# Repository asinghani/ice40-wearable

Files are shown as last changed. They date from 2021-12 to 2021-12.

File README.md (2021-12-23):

# iCE40 Wearables

This repo contains board designs (KiCad) for two iCE40 FPGA-based boards: one in a sewable form-factor and one in a cat-ear form factor.

### Board 1: Sewable

This board is inspired by the [Adafruit Flora](https://www.adafruit.com/product/659) and is meant to be sewn into clothing or accessories. It is shaped as a small circle and has all the components on the front side to allow it to sit flush against a flat surface. It includes the following features:

- iCE40UP5K FPGA
- 16Mb QSPI Flash (GD25Q16CSIGR)
- 16MHz Oscillator (SIT2001BI, multiple frequency options available)
- PWR/DONE/USER LEDs, USER pushbutton
- RGB LED (WS2812)
- 14 Electric Sewing Pads: 12x GPIO, 1x 3V3, 1x GND
- USB-C port
- JST power header
- Tag-Connect programming header

Schematic is in [ice40_sewable_board/schematic.pdf](ice40_sewable_board/schematic.pdf)

An example design (that utilizes the button, USER LED, RGB LED, and one of the sewing pads) is in [ice40_sewable_ref_design/](ice40_sewable_ref_design/)

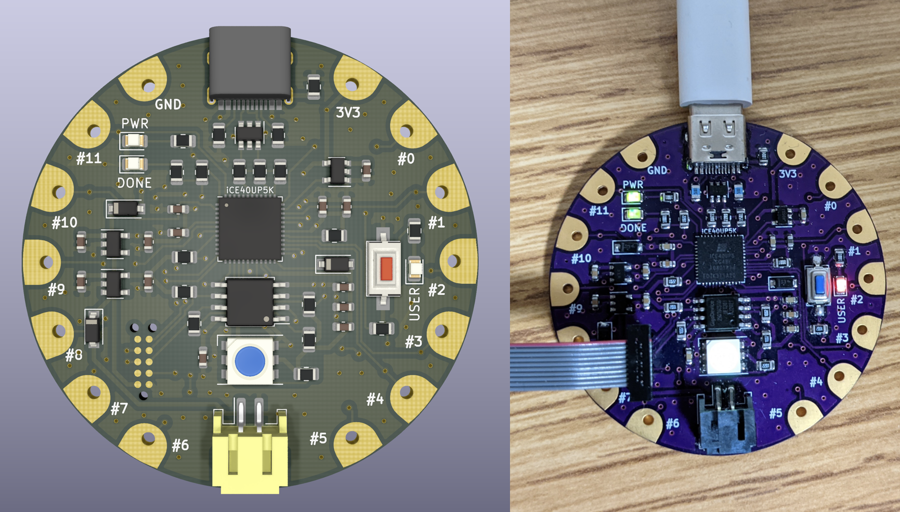
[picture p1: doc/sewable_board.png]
board image


### Board 2: Cat-ears

This board is meant to be shaped like a cat-ear, such that two of them can be worn on a headband (the GPIO pins can be wired together to provide synchronization between the ears). It was designed as a tribute to [YosysHQ](https://www.yosyshq.com/) who develop open-source FPGA software tooling. Each ear includes the following features:

- iCE40UP5K FPGA (internal 48MHz oscillator is used to simplify BOM)
- 16Mb QSPI Flash (GD25Q16CSIGR)
- 7x RGB LED (WS2812)
- Power options: JST power header OR CR2032 coin cell holder
- 2.54mm programming & GPIO header (can be programmed with small wire clips or by soldering)
- Additional GPIO pads on rear side for soldering

Schematic is in [ice40_catears_board/schematic.pdf](ice40_catears_board/schematic.pdf)

An example design (that builds separate modules for the left and right ears, and utilizes the RGB LEDs and GPIO pads) is in [ice40_catears_ref_design/](ice40_catears_ref_design/)

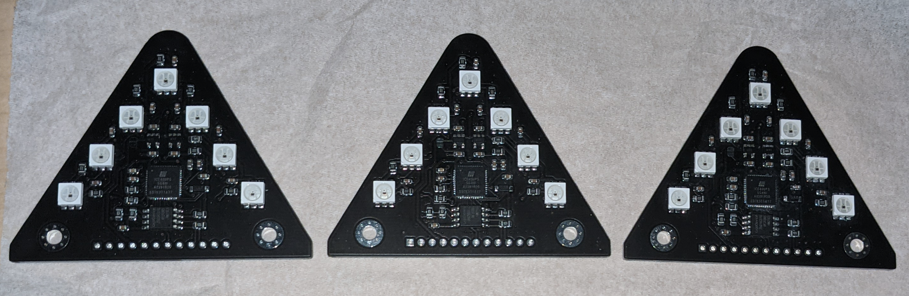
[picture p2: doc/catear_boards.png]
board image


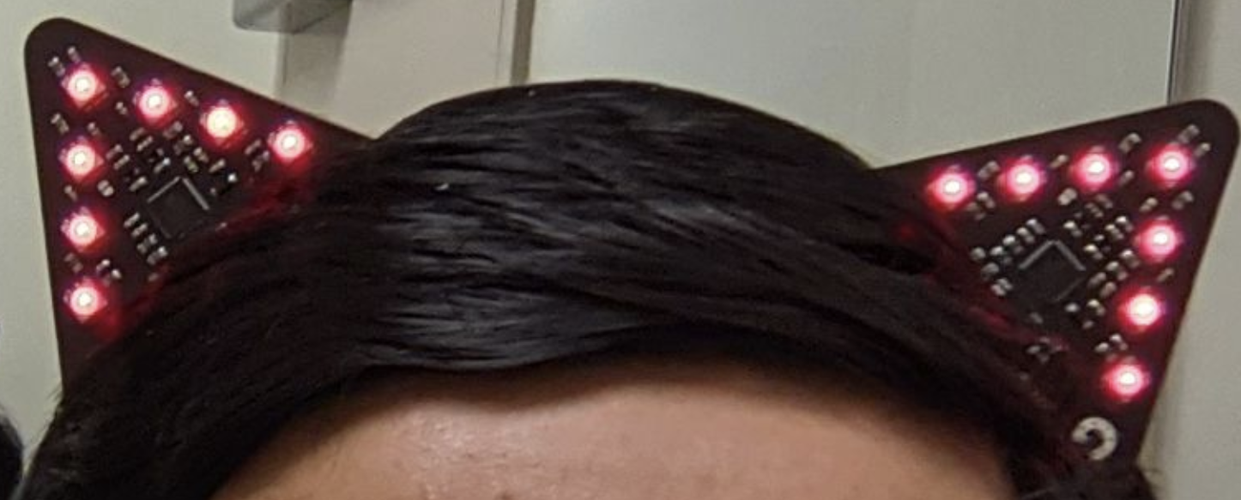
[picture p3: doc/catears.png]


### Acknowledgements

Board design was inspired by [electronutlabs-public/ice-bling](https://gitlab.com/electronutlabs-public/ice-bling) and [icebreaker-fpga/icebreaker](https://github.com/icebreaker-fpga/icebreaker). CMU TechSpark and RoboClub were used for fabrication and materials.

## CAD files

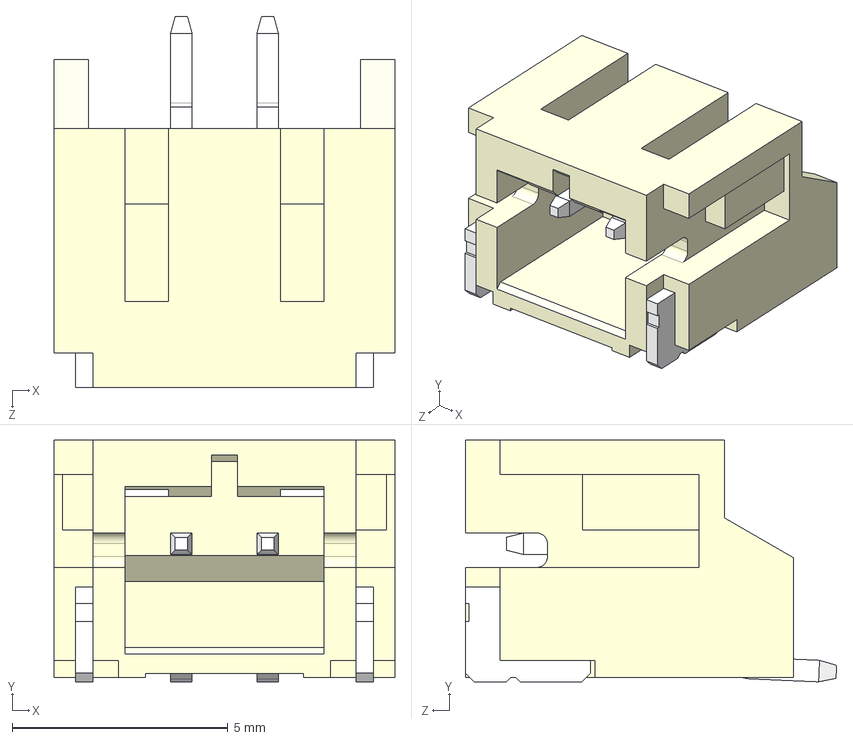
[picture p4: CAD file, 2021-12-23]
ice40_catears_board/3dmodels/JST-S2B-PH-SM4-TB.STEP
7.90 x 5.60 x 8.60 mm

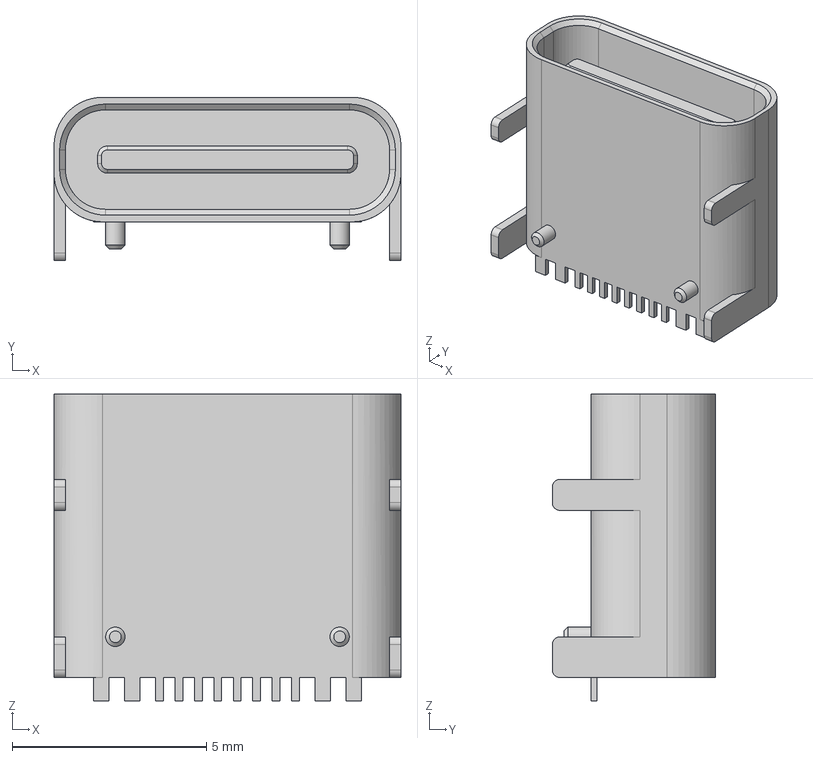
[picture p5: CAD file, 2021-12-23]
ice40_sewable_board/3dmodels/HRO TYPE-C-31-M-12.STEP
8.94 x 4.21 x 7.90 mm

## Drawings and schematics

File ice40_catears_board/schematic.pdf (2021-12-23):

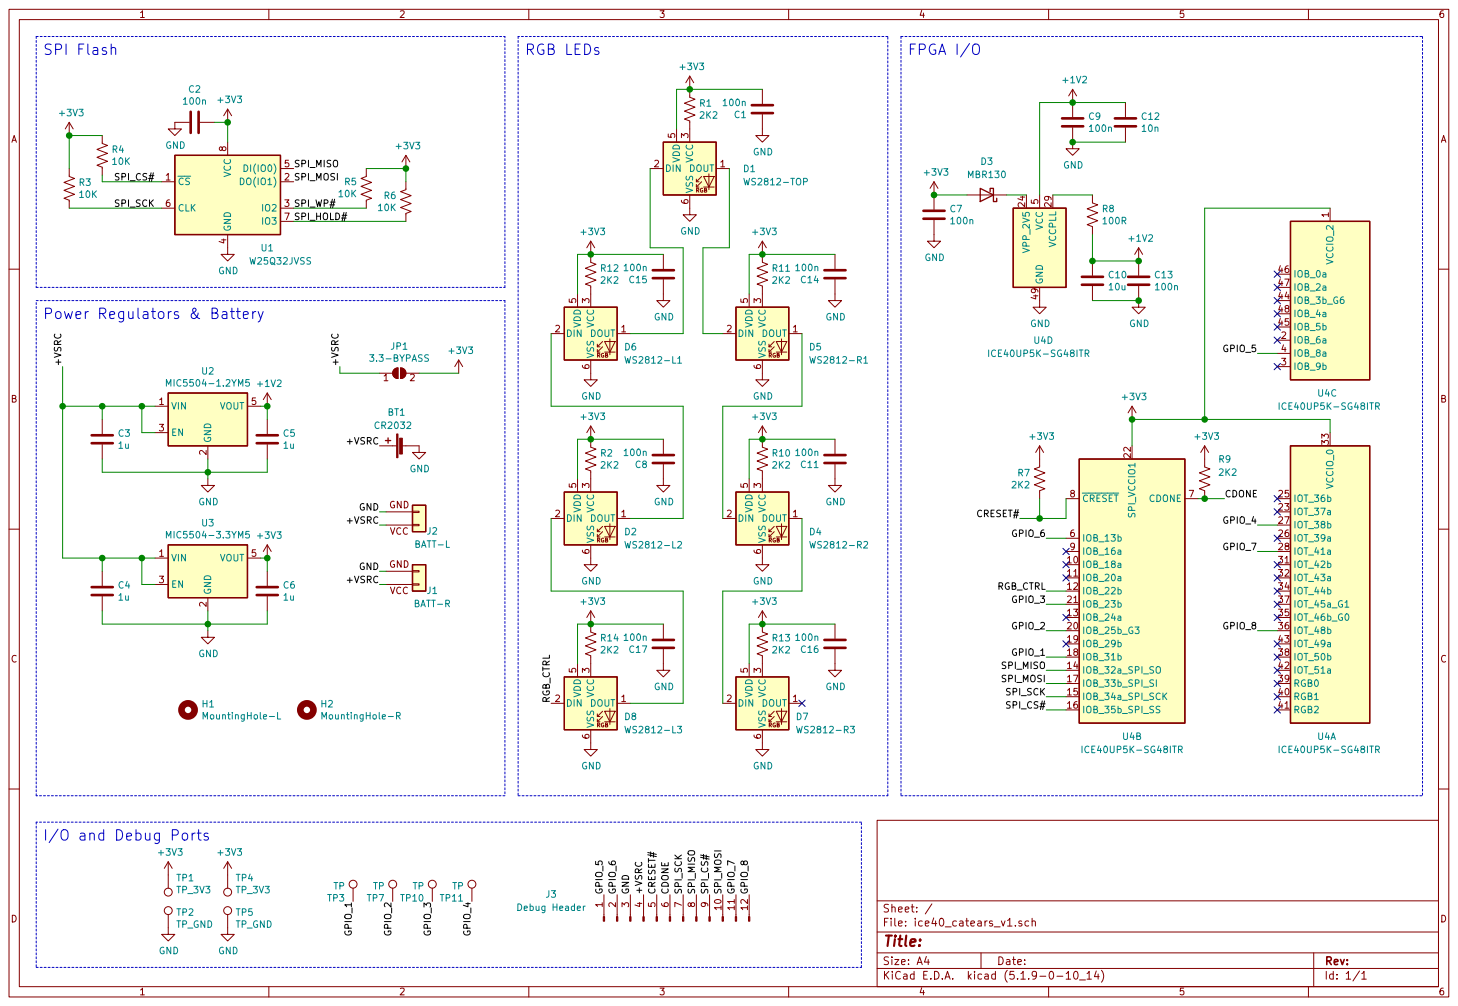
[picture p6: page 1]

File: ice40_catears_v1.sch Sheet: / GND

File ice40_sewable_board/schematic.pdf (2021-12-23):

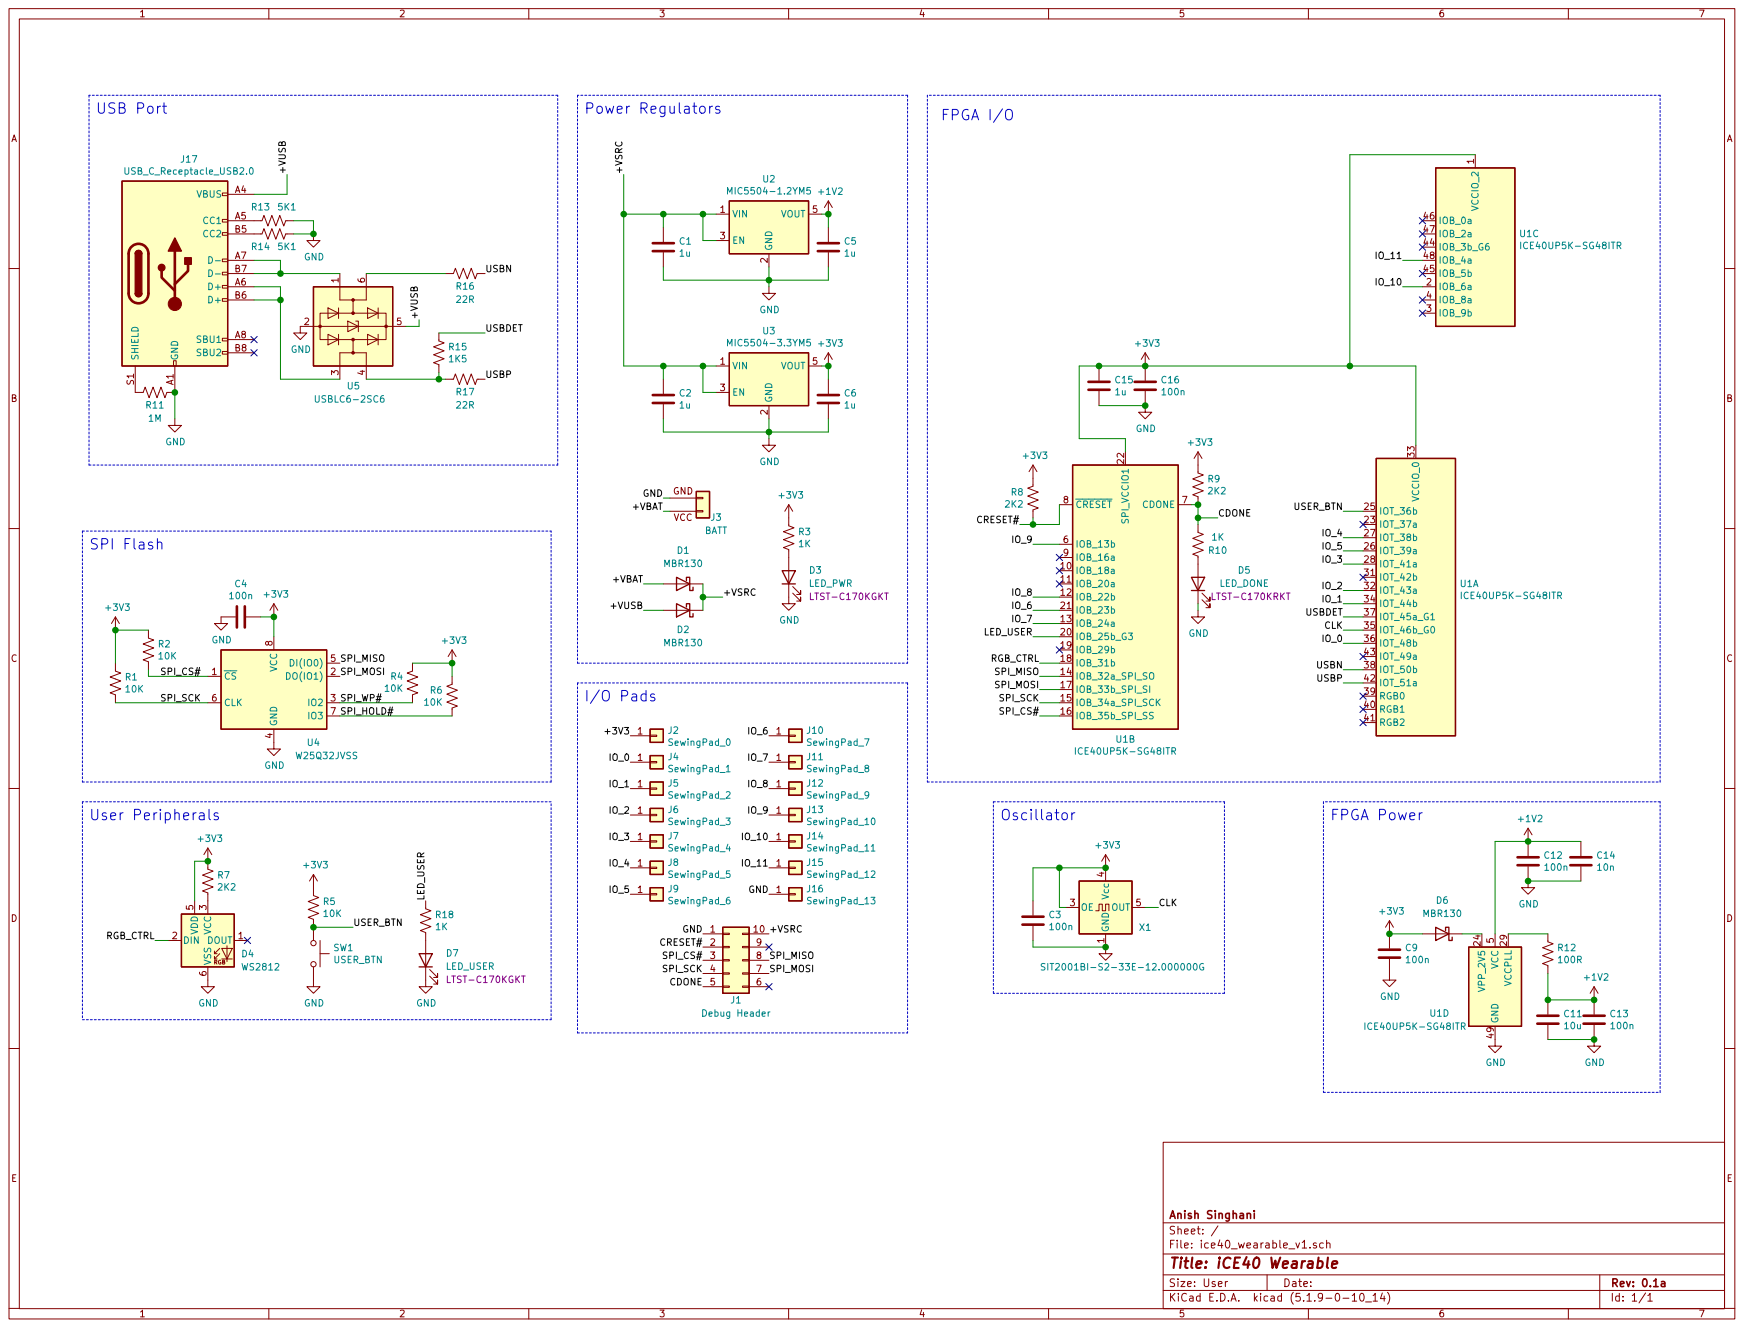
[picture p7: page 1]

File: ice40_wearable_v1.sch Sheet: / Anish Singhani

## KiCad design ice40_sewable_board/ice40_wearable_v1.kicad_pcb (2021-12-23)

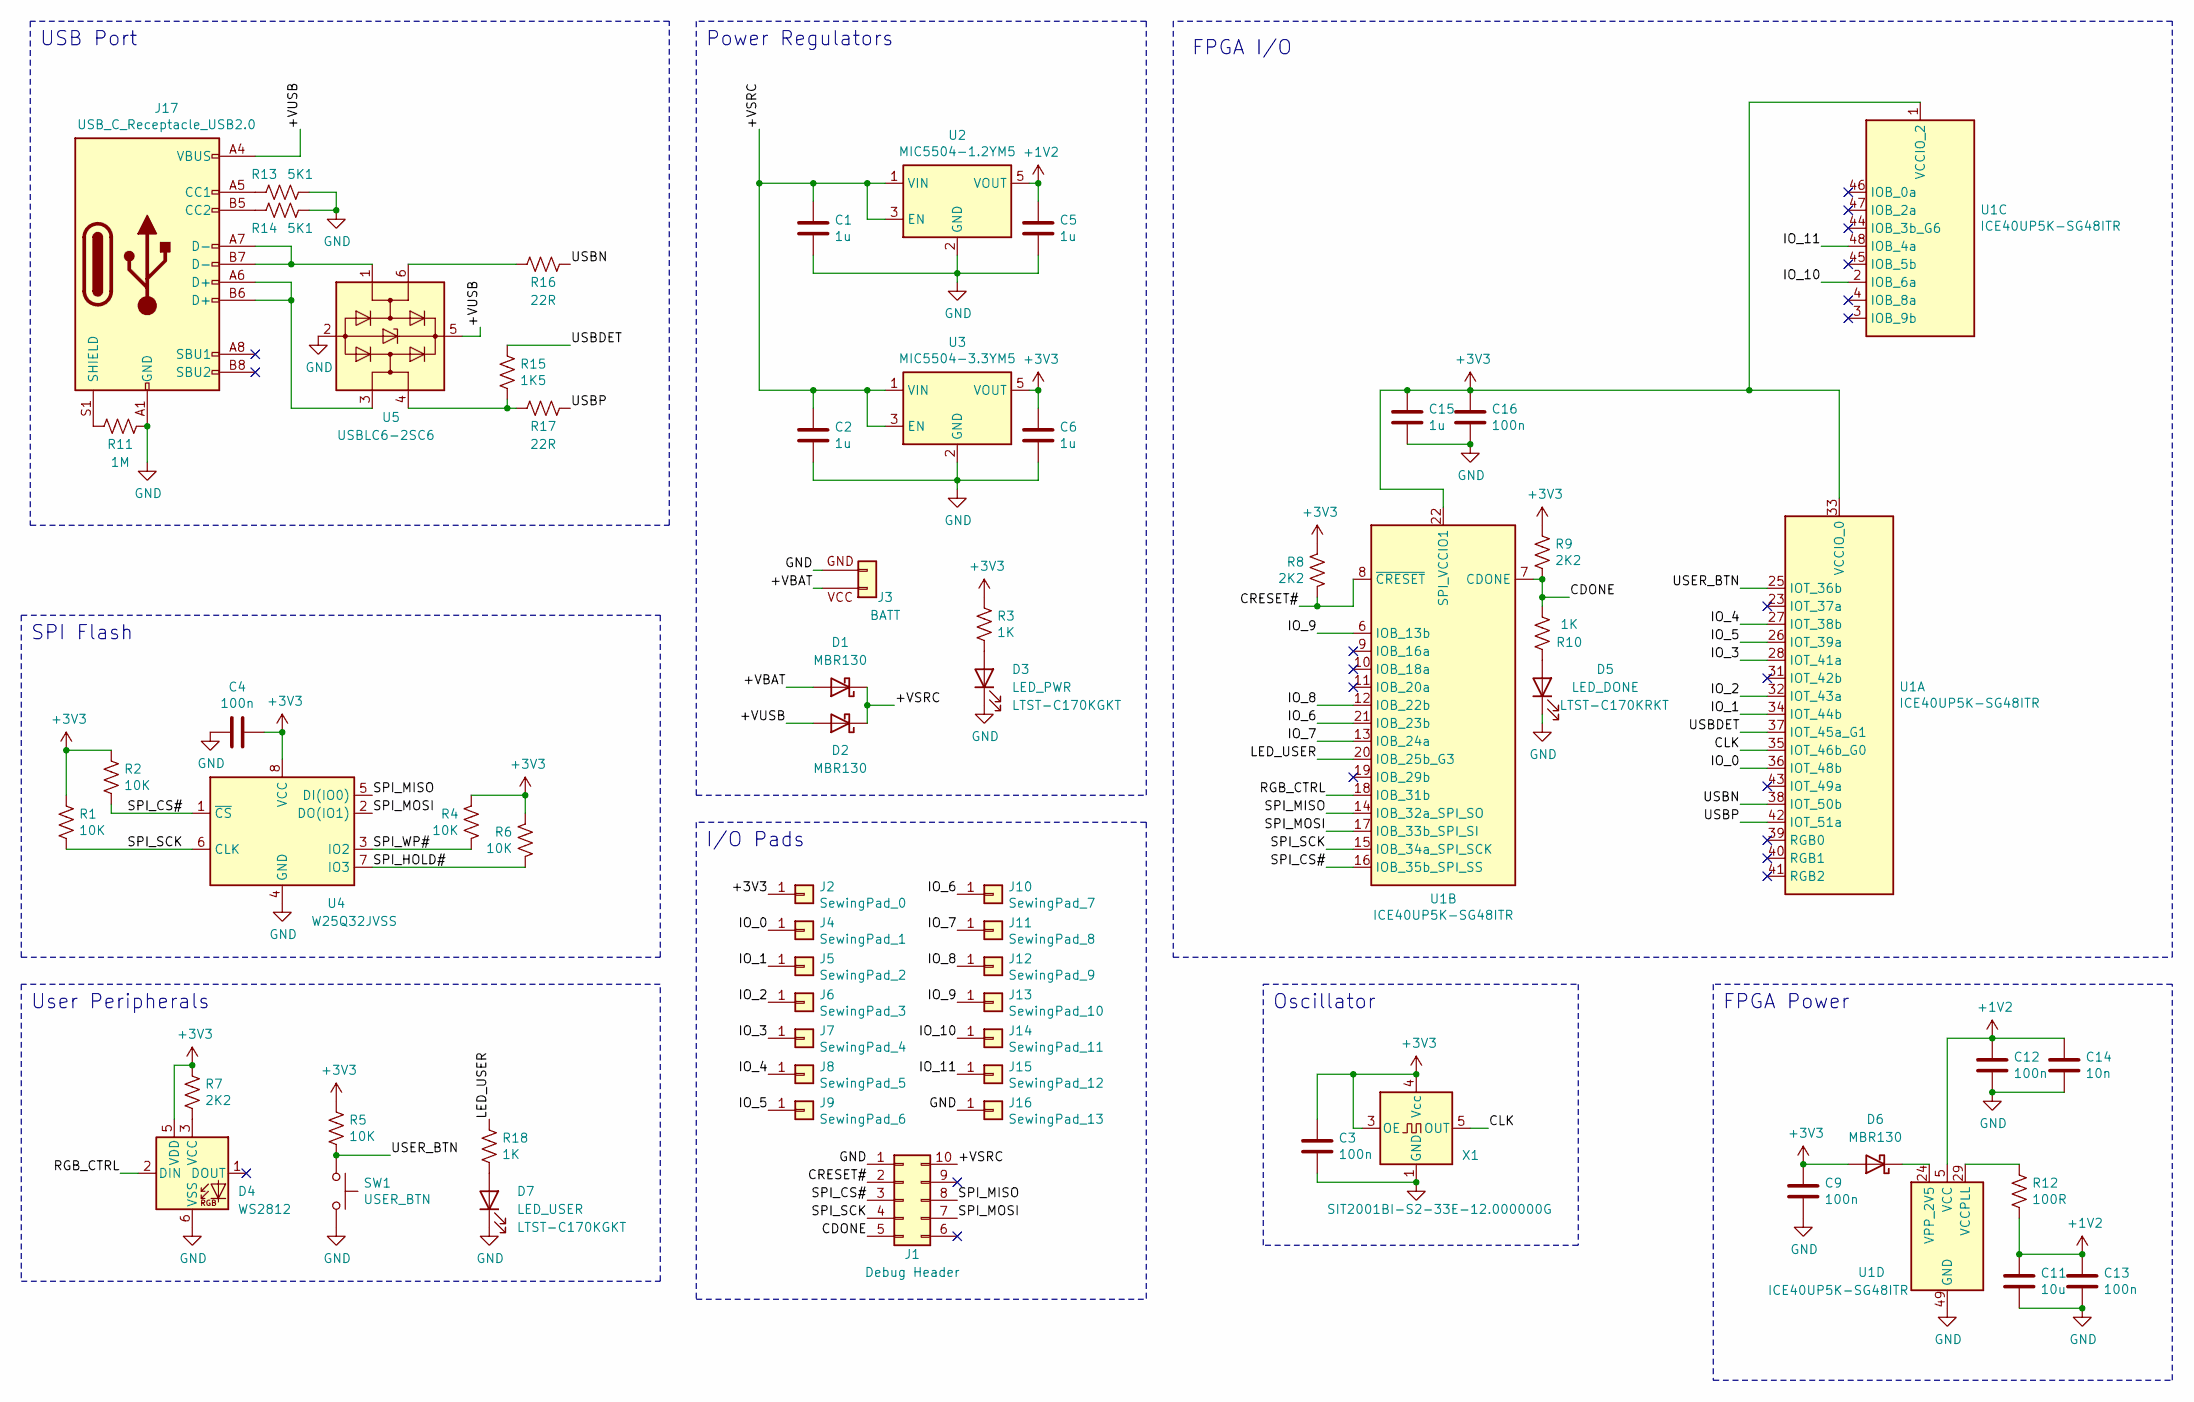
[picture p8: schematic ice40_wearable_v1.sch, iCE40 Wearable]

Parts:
C1, C2, C5, C6, C15: 1u; C_0603_1608Metric
C3, C4, C9, C12, C13, C16: 100n; C_0603_1608Metric
C11: 10u; C_0603_1608Metric
C14: 10n; C_0603_1608Metric
D1, D2, D6: MBR130; D_SOD-123
D3: LED_PWR; LED_0805_2012Metric
D4: WS2812; LED_WS2812_PLCC6_5.0x5.0mm_P1.6mm
D5: LED_DONE; LED_0805_2012Metric
D7: LED_USER; LED_0805_2012Metric
J1: Debug Header; Tag-Connect_TC2050-IDC-NL_2x05_P1.27mm_Vertical_with_bottom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
J2: SewingPad_0; adafruit_sewing_tap
J3: BATT; JST_PH_S2B-PH-SM4-TB_1x02-1MP_P2.00mm_Horizontal
J4: SewingPad_1; adafruit_sewing_tap
J5: SewingPad_2; adafruit_sewing_tap
J6: SewingPad_3; adafruit_sewing_tap
J7: SewingPad_4; adafruit_sewing_tap
J8: SewingPad_5; adafruit_sewing_tap
J9: SewingPad_6; adafruit_sewing_tap
J10: SewingPad_7; adafruit_sewing_tap
J11: SewingPad_8; adafruit_sewing_tap
J12: SewingPad_9; adafruit_sewing_tap
J13: SewingPad_10; adafruit_sewing_tap
J14: SewingPad_11; adafruit_sewing_tap
J15: SewingPad_12; adafruit_sewing_tap
J16: SewingPad_13; adafruit_sewing_tap
J17: USB_C_Receptacle_USB2.0; USB_C_Receptacle_HRO_TYPE-C-31-M-12
R1, R2, R4, R5, R6: 10K; R_0805_2012Metric
R3, R10, R18: 1K; R_0805_2012Metric
R7, R8, R9: 2K2; R_0805_2012Metric
R11: 1M; R_0805_2012Metric
R12: 100R; R_0805_2012Metric
R13, R14: 5K1; R_0805_2012Metric
R15: 1K5; R_0805_2012Metric
R16, R17: 22R; R_0805_2012Metric
SW1: USER_BTN; SW_SPST_CK_RS282G05A3
U1: ICE40UP5K-SG48ITR; QFN-48-1EP_7x7mm_P0.5mm_EP5.6x5.6mm
U2: MIC5504-1.2YM5; SOT-23-5
U3: MIC5504-3.3YM5; SOT-23-5
U4: W25Q32JVSS; SOIC-8_5.23x5.23mm_P1.27mm
U5: USBLC6-2SC6; SOT-23-6
X1: SIT2001BI-S2-33E-12.000000G; SOT-23-5

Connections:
+1V2: C5.1, C11.1, C12.1, C13.1, C14.1, R12.2, U1.5 (VCC), U1.30 (VCC), U2.5 (VOUT)
+3V3: C3.1, C4.1, C6.1, C9.1, C15.1, C16.1, D4.5 (VDD), D6.2 (A), J2.1, R1.1, R2.1, R3.1, R4.2, R5.1, R6.1, R7.1, R8.1, R9.1, U1.1 (VCCIO_2), U1.22 (SPI_VCCIO1), U1.33 (VCCIO_0), U3.5 (VOUT), U4.8 (VCC), X1.3 (OE), X1.4 (Vcc)
/+VBAT: D1.2 (A), J3.1 (+V)
/+VSRC: C1.1, C2.1, D1.1 (K), D2.1 (K), J1.10, U2.1 (VIN), U2.3 (EN), U3.1 (VIN), U3.3 (EN)
/+VUSB: D2.2 (A), J17.A4 (VBUS), J17.A9 (VBUS), J17.B4 (VBUS), J17.B9 (VBUS), U5.5 (VBUS)
/CDONE: J1.5, R9.2, R10.2, U1.7 (CDONE)
/CLK: U1.35 (IOT_46b_G0), X1.5 (OUT)
/CRESET#: J1.2, R8.2, U1.8 (~CRESET)
/IO_0: J4.1, U1.36 (IOT_48b)
/IO_1: J5.1, U1.34 (IOT_44b)
/IO_2: J6.1, U1.32 (IOT_43a)
/IO_3: J7.1, U1.28 (IOT_41a)
/IO_4: J8.1, U1.27 (IOT_38b)
/IO_5: J9.1, U1.26 (IOT_39a)
/IO_6: J10.1, U1.21 (IOB_23b)
/IO_7: J11.1, U1.13 (IOB_24a)
/IO_8: J12.1, U1.12 (IOB_22b)
/IO_9: J13.1, U1.6 (IOB_13b)
/IO_10: J14.1, U1.2 (IOB_6a)
/IO_11: J15.1, U1.48 (IOB_4a)
/LED_USER: R18.1, U1.20 (IOB_25b_G3)
/RGB_CTRL: D4.2 (DIN), U1.18 (IOB_31b)
/SPI_CS#: J1.3, R2.2, U1.16 (IOB_35b_SPI_SS), U4.1 (~CS)
/SPI_HOLD#: R6.2, U4.7 (IO3)
/SPI_MISO: J1.8, U1.14 (IOB_32a_SPI_SO), U4.5 (DI(IO0))
/SPI_MOSI: J1.7, U1.17 (IOB_33b_SPI_SI), U4.2 (DO(IO1))
/SPI_SCK: J1.4, R1.2, U1.15 (IOB_34a_SPI_SCK), U4.6 (CLK)
/SPI_WP#: R4.1, U4.3 (IO2)
/USBDET: R15.1, U1.37 (IOT_45a_G1)
/USBN: R16.2, U1.38 (IOT_50b)
/USBP: R17.2, U1.42 (IOT_51a)
/USER_BTN: R5.2, SW1.1, U1.25 (IOT_36b)
GND: C1.2, C2.2, C3.2, C4.2, C5.2, C6.2, C9.2, C11.2, C12.2, C13.2, C14.2, C15.2, C16.2, D3.1 (K), D4.6 (VSS), D5.1 (K), D7.1 (K), J1.1, J3.2 (GND), J16.1, J17.A1 (GND), J17.A12 (GND), J17.B1 (GND), J17.B12 (GND), R11.2, R13.2, R14.2, SW1.2, U1.49 (GND), U2.2 (GND), U3.2 (GND), U4.4 (GND), U5.2 (GND), X1.1 (GND)
unnamed: D3.2 (A), R3.2
unnamed: D4.3 (VCC), R7.2
unnamed: D5.2 (A), R10.1
unnamed: D6.1 (K), U1.24 (VPP_2V5)
unnamed: D7.2 (A), R18.2
unnamed: J17.A5 (CC1), R13.1
unnamed: J17.A6 (D+), J17.B6 (D+), U5.3 (I/O2)
unnamed: J17.A7 (D-), J17.B7 (D-), U5.1 (I/O1)
unnamed: J17.B5 (CC2), R14.1
unnamed: J17.S1 (SHIELD), R11.1
unnamed: R12.1, U1.29 (VCCPLL)
unnamed: R15.2, R17.1, U5.4 (I/O2)
unnamed: R16.1, U5.6 (I/O1)

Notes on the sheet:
User Peripherals
SPI Flash
Power Regulators
USB Port
FPGA Power
FPGA I/O
I/O Pads
Oscillator

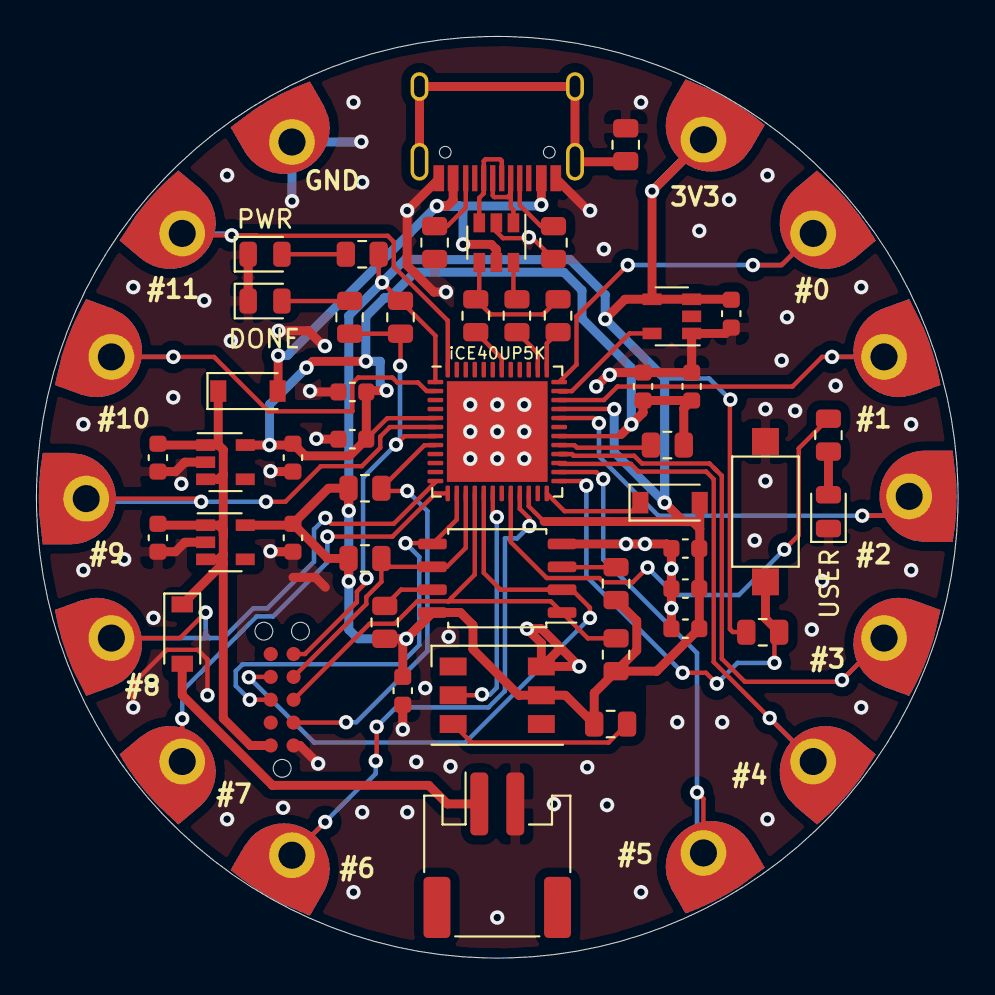
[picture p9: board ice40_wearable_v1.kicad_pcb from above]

Board: 2 copper layers, 51.2 x 51.2 mm, 62 parts (0 on the bottom side), 46 nets.

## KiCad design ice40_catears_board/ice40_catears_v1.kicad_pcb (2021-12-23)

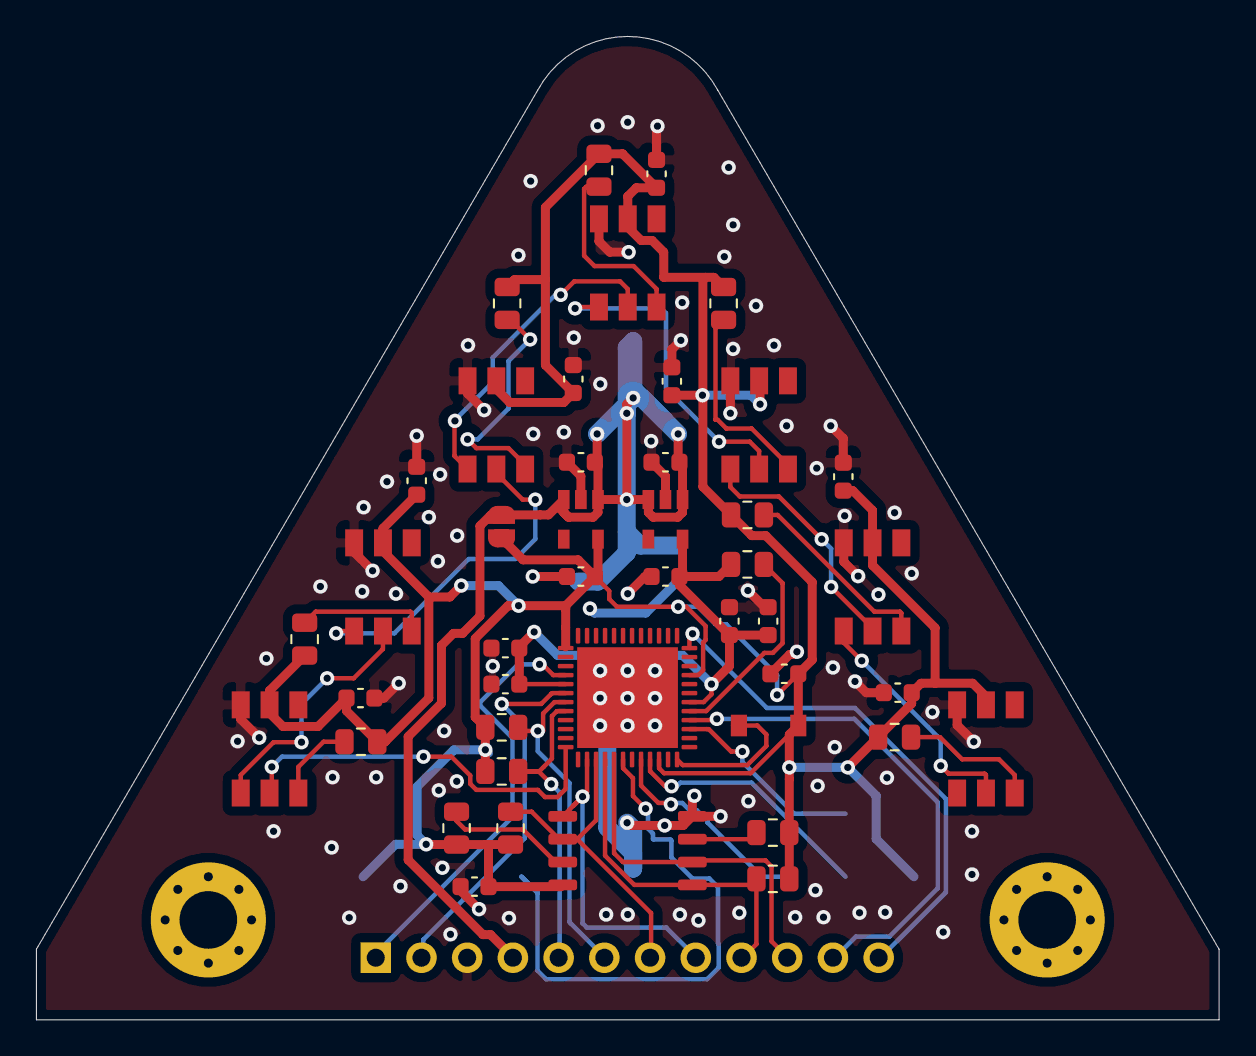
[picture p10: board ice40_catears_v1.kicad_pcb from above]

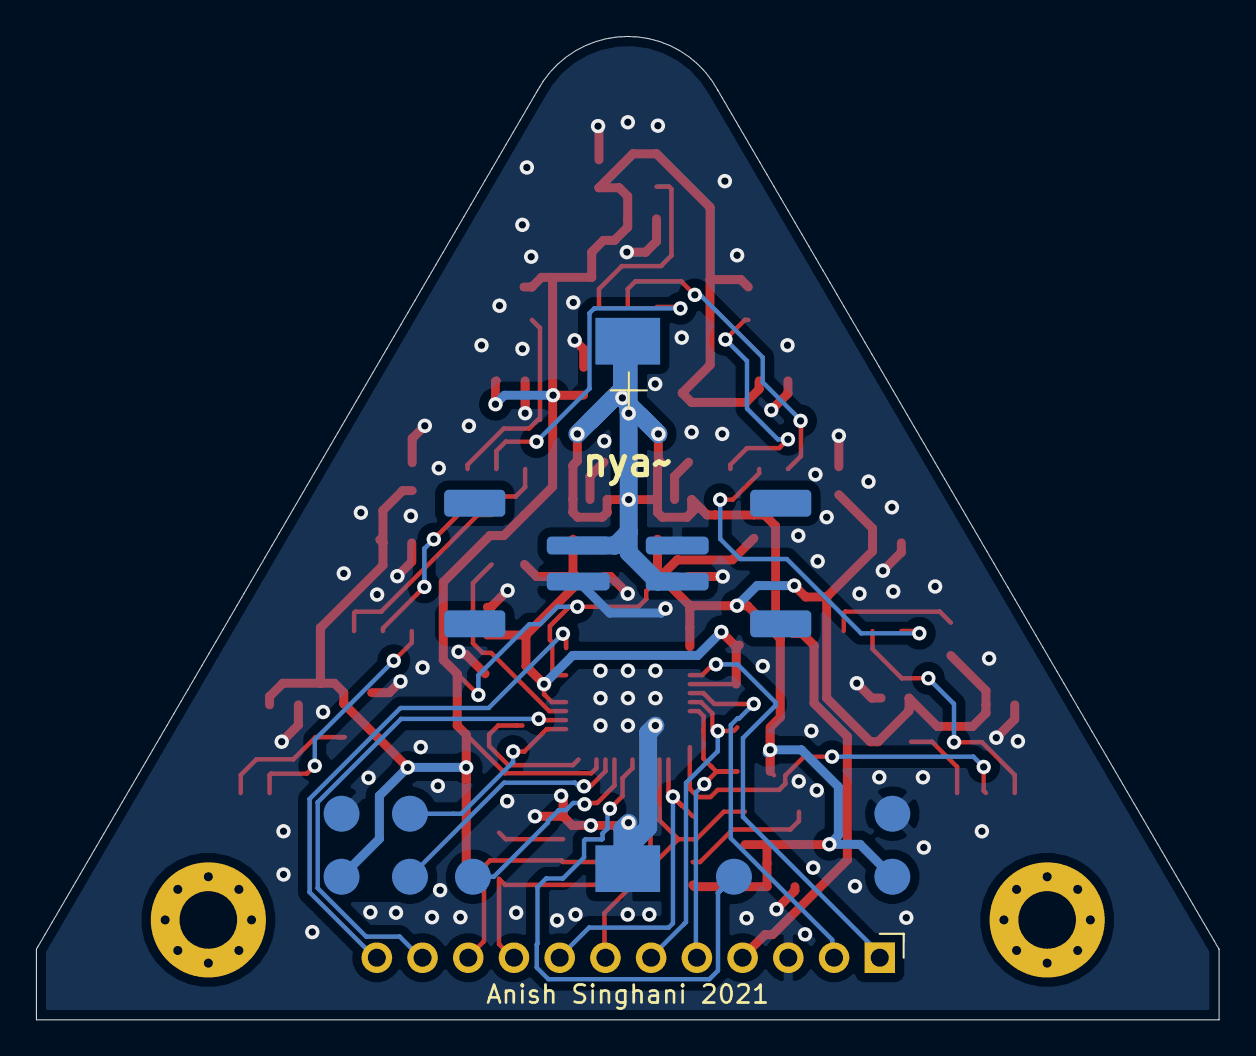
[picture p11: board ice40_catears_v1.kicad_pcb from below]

Board: 2 copper layers, 65.7 x 54.6 mm, 58 parts (12 on the bottom side), 36 nets.

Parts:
BT1: CR2032; BatteryHolder_Keystone_1060_1x2032
C1, C2, C7, C8, C9, C11, C13, C14, C15, C16, C17: 100n; C_0603_1608Metric
C3, C4, C5, C6: 1u; C_0603_1608Metric
C10: 10u; C_0603_1608Metric
C12: 10n; C_0603_1608Metric
D1: WS2812-TOP; LED_WS2812_PLCC6_5.0x5.0mm_P1.6mm
D2: WS2812-L2; LED_WS2812_PLCC6_5.0x5.0mm_P1.6mm
D3: MBR130; D_SOD-123
D4: WS2812-R2; LED_WS2812_PLCC6_5.0x5.0mm_P1.6mm
D5: WS2812-R1; LED_WS2812_PLCC6_5.0x5.0mm_P1.6mm
D6: WS2812-L1; LED_WS2812_PLCC6_5.0x5.0mm_P1.6mm
D7: WS2812-R3; LED_WS2812_PLCC6_5.0x5.0mm_P1.6mm
D8: WS2812-L3; LED_WS2812_PLCC6_5.0x5.0mm_P1.6mm
H1: MountingHole-L; MountingHole_3.2mm_M3_Pad_Via
H2: MountingHole-R; MountingHole_3.2mm_M3_Pad_Via
J1: BATT-R; JST_PH_S2B-PH-SM4-TB_1x02-1MP_P2.00mm_Horizontal
J2: BATT-L; JST_PH_S2B-PH-SM4-TB_1x02-1MP_P2.00mm_Horizontal
J3: Debug Header; PinHeader_1x12_P2.54mm_Vertical
JP1: 3.3-BYPASS; SolderJumper-2_P1.3mm_Open_RoundedPad1.0x1.5mm
R1, R2, R7, R9, R10, R11, R12, R13, R14: 2K2; R_0805_2012Metric
R3, R4, R5, R6: 10K; R_0805_2012Metric
R8: 100R; R_0805_2012Metric
TP1, TP4: TP_3V3; TestPoint_Pad_D2.0mm
TP2, TP5: TP_GND; TestPoint_Pad_D2.0mm
TP3, TP7, TP10, TP11: TP; TestPoint_Pad_D2.0mm
U1: W25Q32JVSS; SOIC-8_5.23x5.23mm_P1.27mm
U2: MIC5504-1.2YM5; SOT-23-5
U3: MIC5504-3.3YM5; SOT-23-5
U4: ICE40UP5K-SG48ITR; QFN-48-1EP_7x7mm_P0.5mm_EP5.6x5.6mm

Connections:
+1V2: C5.1, C9.1, C10.1, C12.1, C13.1, R8.2, U2.5, U4.5, U4.30
+3V3: C1.2, C2.1, C6.1, C7.1, C8.2, C11.2, C14.2, C15.2, C16.2, C17.2, D1.5, D2.5, D3.2, D4.5, D5.5, D6.5, D7.5, D8.5, JP1.2, R1.1, R2.1, R3.1, R4.1, R5.2, R6.1, R7.1, R9.1, R10.1, R11.1, R12.1, R13.1, R14.1, TP1.1, TP4.1, U1.8, U3.5, U4.1, U4.22, U4.33
/+VSRC: BT1.1, C3.1, C4.1, J1.1, J2.1, J3.4, JP1.1, U2.1, U2.3, U3.1, U3.3
/CDONE: J3.6, R9.2, U4.7
/CRESET#: J3.5, R7.2, U4.8
/GPIO_1: TP3.1, U4.18
/GPIO_2: TP7.1, U4.20
/GPIO_3: TP10.1, U4.21
/GPIO_4: TP11.1, U4.27
/GPIO_5: J3.1, U4.4
/GPIO_6: J3.2, U4.6
/GPIO_7: J3.11, U4.28
/GPIO_8: J3.12, U4.36
/RGB_CTRL: D8.2, U4.12
/SPI_CS#: J3.9, R4.2, U1.1, U4.16
/SPI_HOLD#: R6.2, U1.7
/SPI_MISO: J3.8, U1.5, U4.14
/SPI_MOSI: J3.10, U1.2, U4.17
/SPI_SCK: J3.7, R3.2, U1.6, U4.15
/SPI_WP#: R5.1, U1.3
GND: BT1.2, C1.1, C2.2, C3.2, C4.2, C5.2, C6.2, C7.2, C8.1, C9.2, C10.2, C11.1, C12.2, C13.2, C14.1, C15.1, C16.1, C17.1, D1.6, D2.6, D4.6, D5.6, D6.6, D7.6, D8.6, J1.2, J2.2, J3.3, TP2.1, TP5.1, U1.4, U2.2, U3.2, U4.49
unnamed: D1.1, D5.2
unnamed: D1.2, D6.1
unnamed: D1.3, R1.2
unnamed: D2.1, D6.2
unnamed: D2.2, D8.1
unnamed: D2.3, R2.2
unnamed: D3.1, U4.24
unnamed: D4.1, D7.2
unnamed: D4.2, D5.1
unnamed: D4.3, R10.2
unnamed: D5.3, R11.2
unnamed: D6.3, R12.2
unnamed: D7.3, R13.2
unnamed: D8.3, R14.2
unnamed: R8.1, U4.29

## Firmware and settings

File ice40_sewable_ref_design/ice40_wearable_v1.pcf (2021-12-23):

########################################################################
# Main constraints file for iCE40 wearable board
########################################################################

# Main clock (16 MHz)
set_io clk 35

# Direct USB
set_io usbp   42
set_io usbn   38
set_io usbdet 37

# SPI Flash
set_io flash_csn 16 # SPI_CS# on schem
set_io flash_sck 15 # SPI_SCK on schem
set_io flash_io0 14 # SPI_MISO on schem
set_io flash_io1 17 # SPI_MOSI on schem

# Sewing Pad I/O Ports
set_io io_0  36
set_io io_1  34
set_io io_2  32
set_io io_3  28
set_io io_4  27
set_io io_5  26
set_io io_6  21
set_io io_7  13
set_io io_8  12
set_io io_9  6
set_io io_10 2
set_io io_11 48

# On-board Peripherals
set_io led_user   20
set_io btn_user_n 25
set_io rgb_led    18
